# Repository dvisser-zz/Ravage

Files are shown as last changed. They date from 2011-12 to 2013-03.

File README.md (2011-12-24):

# RavAGE - A Toyota 4AGE specific hardware solution for FreeEMS.

### Introduction

The name "RavAGE" is something relating to the Toyota 4-'AGE' engine. The aim of
the RavAGE project is to create a hardware solution for FreeEMS that caters to
the needs of the Toyota 4AGE engines (16V and 20V). It may also be used on most
4/6cyl engine setups with minimal to no modifications required. 

Please see [FreeEMS.org](http://freeems.org) for the most up to date information
and links for this project and all of the other aspects of the FreeEMS project.

### Goals

Core IO specs:

 - 1 FTDI USB (bus powered) communications that are opto coupled to the CPU. 
 - 3 RPM/Position inputs via MAX99xx devices to take advantage of the 3 in the 4AGE CAS assemblies.
 - 8 Standard 'CORE' analogue inputs. 
 - 6 ignition drives (external igniters ONLY).
 - 6 injector drives (high-z ONLY).
 - 5 Ground connections (ECU GND, INJ GND, IGN GND, ACC GND and Analogue Input GND).
 - 3 "12V" connections (+12V CONSTANT,+12V SWITCHED for BRV and key-on signal and +12V ACC for accessory functions).
 - 3 overkill relay drive's (FAN RELAY, FUEL PUMP RELAY and VVT SOLENOID).
 - 1 switched +5V output for TPS and EXT MAP.
 - 2 outputs suitable for driving a 3-wire Toyota Idle Speed Control Valve (+12V ACC, PWM Non-Inverted and PWM Inverted).
 - 2 spare digital inputs.
 - 2 spare analogue inputs (option to configure as temperature or voltage input).
 - 2 spare low side drives.

PCB Size is to be as small as possible, but attention must be paid when choosing
a connector as this will more than likely be the deciding factor on the overall
size. Worst-case scenario will be a PCB that is 100mm x 80mm, which is still
small and allows for the use of some sort of "nice" connector. It could be
made smaller, but at this size, there will be room for extra general purpose
output drivers, analogue inputs, etc.

### Status

For the most up to date status information for the project, refer to the TODO.md
file which is maintained in sync with the schematics by a small team who verify
each other's work.

### Changes

Please send any changes that you make to RavAGE back upstream to [Dan Visser's copy](https://github.com/dvisser/Ravage)

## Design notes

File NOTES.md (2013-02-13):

# Design Detail Notes

This file is to contain various details that aren't appropriate to show in the
schematic such as default specifications for passive components and deviations
from those defaults.

 - Unless otherwise noted, all resistors to be 1% metal film construction and 100mW power handling.
 - Pull up resistors on thermistor inputs, voltage measurement divider networks, and regulator V setting network to be 0.1% metal film.
 - Capacitors 1.0uF and under to be X7R ceramic, and in very small values, C0G/NP0.
 - All polarised capacitors are tantalumn, 35V minimum when exposed to battery voltage, 10V minimum for internal regulated voltages.
 - VR input resistors to be 200V rated and have a power rating of 500mW or greater. 
 - VR input capacitors must be 200V rated. 
 - VR 5k shunt resistor must be 2W or greater
 - ADC 470R current limiting resistors must be 250mW or greater. 
 - Ignitor drive output 200R current limiting resistors must be 2W or greater. 
 - Ferrite bead to 5V USB input before caps to prevent USB power noise corrupting comms should be something like this: http://nz.element14.com/murata/blm18pg300sn1d/ferrite-bead-0603-case-30ohm/dp/1515741RL
 - 1k input resistor and 5v6 zener on digital input circuits should be rated to 250mW minimum.
 - All LEDs should have 2.4k resistors except where noted in the schematics.
 - For best ADC accuracy, ensure that "+5V SWITCHED" voltage is less than or equal to "+5V MICRO" 
 - After construction measure quiescent current and ensure that it's below ~100mA. If not the clamp and power supply are probably fighting. Look at the 5V rail, if high, tweak resistors to trim it down, if not, tweak clamp resistors to trim it up.

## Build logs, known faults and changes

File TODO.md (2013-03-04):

### TODO

Items listed here should be changed one at a time, and the line marked done, this
file and the changed files committed together. After a session of N changes the
PDF should be updated and pushed. The PDF should not be updated with each and
every change as there is no benefit and a binary repository size drawback.

 - Fred and Dan to discuss/review reverse polarity behaviour of the current schematic and connection topology. Next skype.
 - Correct lables on RPM1a inputs, which are backward. Spotted by Dan, good work, sir! :-)
 - DONE, Fix the load jumper and CEL circuit by adding a resistor between it and the CPU like this: http://stuff.fredcooke.com/LoadAndCELCorrectJumperTopology.png
 - Deferrable: Spend some time to properly tune the ADC filter capacitor values - Fred and Dan and others
 - Deferrable: Experiment with layouts to validate pin arrangement selection for header, and decide if Knock/RS232/Dual-reg setup is possible to fit for 0.1

### Once branched for layout-0.1-alpha (RC2)

Fred and Dan to do this together like last time in a session.

 - Remove the SD card sheet, 3.3V power supply, and X the pins on the CPU sheet, etc.
 - Correct annotation sheet order before annotating
 - Annotate the schematics with designators
 - Update all notes with designators to match new numbering (remove ?)
 - Generate new PDF for review
 - Update the TODO to reflect current goals on branch and new single hash of all files post annotation
 - Tag repository as Schem-0.1-alpha-RC2
 - Import BOM from RC1, adjust references to suit new schematic annotations, commit BOM (do we need PDF of this? I think not.)

### Still To Add/Do

Known issues which don't have a solution 100% nailed down yet.

Required for a final board revision to be top quality:

 1. Confirm pin selection for simple bit banged IO like tacho etc: Fred + others: http://forum.diyefi.org/viewtopic.php?f=8&t=1676
 2. Finalise selection of wakeup pin - Fred http://forum.diyefi.org/viewtopic.php?f=8&t=1266
 3. Power supply page - requires design, discuss http://forum.diyefi.org/viewtopic.php?f=58&t=1478

Easy stuff to do last:

 1. Tune the ADC input filters - Fred + consultation
 2. Annotate all components in the schematics
 3. Add to and correct the NOTES.md file

Stuff that's still in progress, but good enough already:

 1. DONE! (enough) Develop new improved SM - Fred http://forum.diyefi.org/viewtopic.php?f=8&t=1232

And perhaps more.

### SD card sheet changes

Discuss all SD card sheet changes before doing anything, skype, IRC and forum: http://forum.diyefi.org/viewtopic.php?f=58&t=1479

 - Improve layout of SD card sheet - Preston wants to do this
 - Move 3.3V regulator to 12V input such that sharp current changes don't affect our analogue stuff
 - Use regulator with enable input and parallel with analogue enable on 5V setup
 - Reduce post reg capacitor to 47uF tantalum
 - Change 1.0uF to 0.1uF ceramics on both sides of 3.3V reg
 - Move all 3.3V power supply caps to power supply sheet

All pages that are changed must be rechecked and enter another cycle of fix and
then check or be confirmed good and then locked down.

### Connector pin ordering

At least four concerns guide the selection of pin to function mappings. By far
the most important of these is noise considerations. For this reason the layout
should maintain the following block ordering:

 1. RPM Inputs (hyper sensitive)
 2. Analogue Inputs (and 5V/Ground for them) (very sensitive)
 3. Digital Inputs (very sensitive)
 4. Ignition Outputs, low current (not sensitive, not noisy)
 5. Fuel pump relay drive (not sensitive, potential to be noisy)
 6. Spare LSD Outputs (not sensitive, usually noisy, when used)
 7. ISCV Outputs (not sensitive, usually noisy, when used)
 8. Injector Outputs (not sensitive, always noisy, when used)
 9. Power and Grouds (not sensitive, grounds always noisy)

The other three concerns are these:

 1. Intuitive User Order
 2. Fine grain routing
 3. Schematic Aesthetics

1 and 2 are of similar importance, and 3 should take a back seat to the others,
while still being kept in mind for ease of comprehension. As such the designers
are free to reorder pins of this sheet during the layout process to facilitate a
better, lower noise, simpler, cleaner, more compact, more comprehensible for the
user layout. Aside from the block ordering, the page should be kept with all
inputs and ignition drivers on the left and all high current and high noise
connections on the right. This sheet reordering does not need to follow the
usual process of agree, TODO, action, and can be done at the designers will.
Although this breaks with the process, it provides significant benefits in both
speed of development and quality of development. Thus it is worth doing this way.

The spare pins header sheet is subject to the same freedoms for layout reasons.

Pin ordering follows this diagram, except the grounds have been rearranged http://stuff.fredcooke.com/RavagePinOutAttempt2.png

### Pre-Layout Lock Down

As each sheet becomes a perfect representation of what we want to see in RavAGE
it will get locked. That is to say, no further changes to that sheet's source
.SchDoc file will be allowed without agreement between all key players.

Locked sheets will be listed here as they are finalised:

 - Spare IO Header @ NO pending possible rearrangement
 - Core analogue inputs @ NO pending value selection
 - Extra analogue inputs @ NO pending value selection
 - USE 0.1 TO TEST: @ b36bb33d Digital and wake up inputs @ NO pending wake up testing
 - Connector pin out @ ecdaed700b58eaaf16ad0ddf4c48198efca5d85a
 - CPU and buses, etc @ 14eae84ad1f2c094e9d5b6bee46bd3429c172d74
 - USB communications @ e70d478d8635a083402ecfb5f5f076b4fc3c8185
 - RS232 communications @ 247e1f109145382aaa98ed5c90c7676b9f4068cd
 - RPM conditioned inputs @ c40a0885fad16cf92aaf213e950141aef8fa67e1
 - Knock sensor inputs @ 1450ad98dc2e1c864d0d5789b42a16420bbd773e
 - Igniter output drivers @ fc591f538e7f880f76d490ce6b23da58f4e1e481
 - Injector output drivers @ 7ad534dc22ba7a4618d42d22ae2bb547ddda230f
 - GP low side drivers @ 0e0ec7b1f4f0095ec0caf7929a33b819e120481e
 - 3-wire ISCV drivers @ 7ad534dc22ba7a4618d42d22ae2bb547ddda230f
 - OK FOR 0.1 @ e50be379d But not final. Power supplies @ NO pending discussion and design
 - UNUSED FOR 0.1: SD card slot @ NO pending multiple changes

### PDF Sheet Ordering

All sheets except for the CPU/navigation sheet will be A4 size. The CPU sheet
needs to be larger to fit the minimum required items on it. The sheet ordering
should be kept consistent on every commit. Preferred ordering is as follows.

 1.  CPU, decoupling, etc
 2.  Power supplies
 3.  USB communications
 4.  RS232 communications
 5.  RPM conditioned inputs
 6.  Core analogue inputs
 7.  Extra analogue inputs
 8.  Digital and wake up inputs
 9.  Knock sensor inputs
 10. Igniter output drivers
 11. Injector output drivers
 12. GP low side drivers
 13. 3-wire ISCV drivers
 14. SD card slot
 15. Spare IO Header
 16. Connector pin out

### Space Constraints

Due to the target board size and the level of things included so far, some
items could get cut when layout starts and we start getting a feel for
realistic limitations. The current plan is a 2-layer board with all features
that are currently in the schematics. I will list the possible changes below.

 - Change from 2-layer to 4-layer. Benefits more compact, better noise resistance. Drawbacks, more expensive, mildly less hackable.
 - Remove SD card slot and 3.3V power supply components
 - Remove RS232 interface for LC-1 and other products
 - Remove knock sensing interface circuit
 - Drop always-on support and RTC in favour of a simpler key switched design
 - No built in BDM header included, program via bed of nails or edge connector
 - Less spare and GP and diagnostic drivers and protection circuits
 - Less injector and ignition drivers, 4 minimum each, optimally 6 ignition, 8 injection

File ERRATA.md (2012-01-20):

# RavAGE Errata

The project is still under development so, by definition, there is no errata yet.

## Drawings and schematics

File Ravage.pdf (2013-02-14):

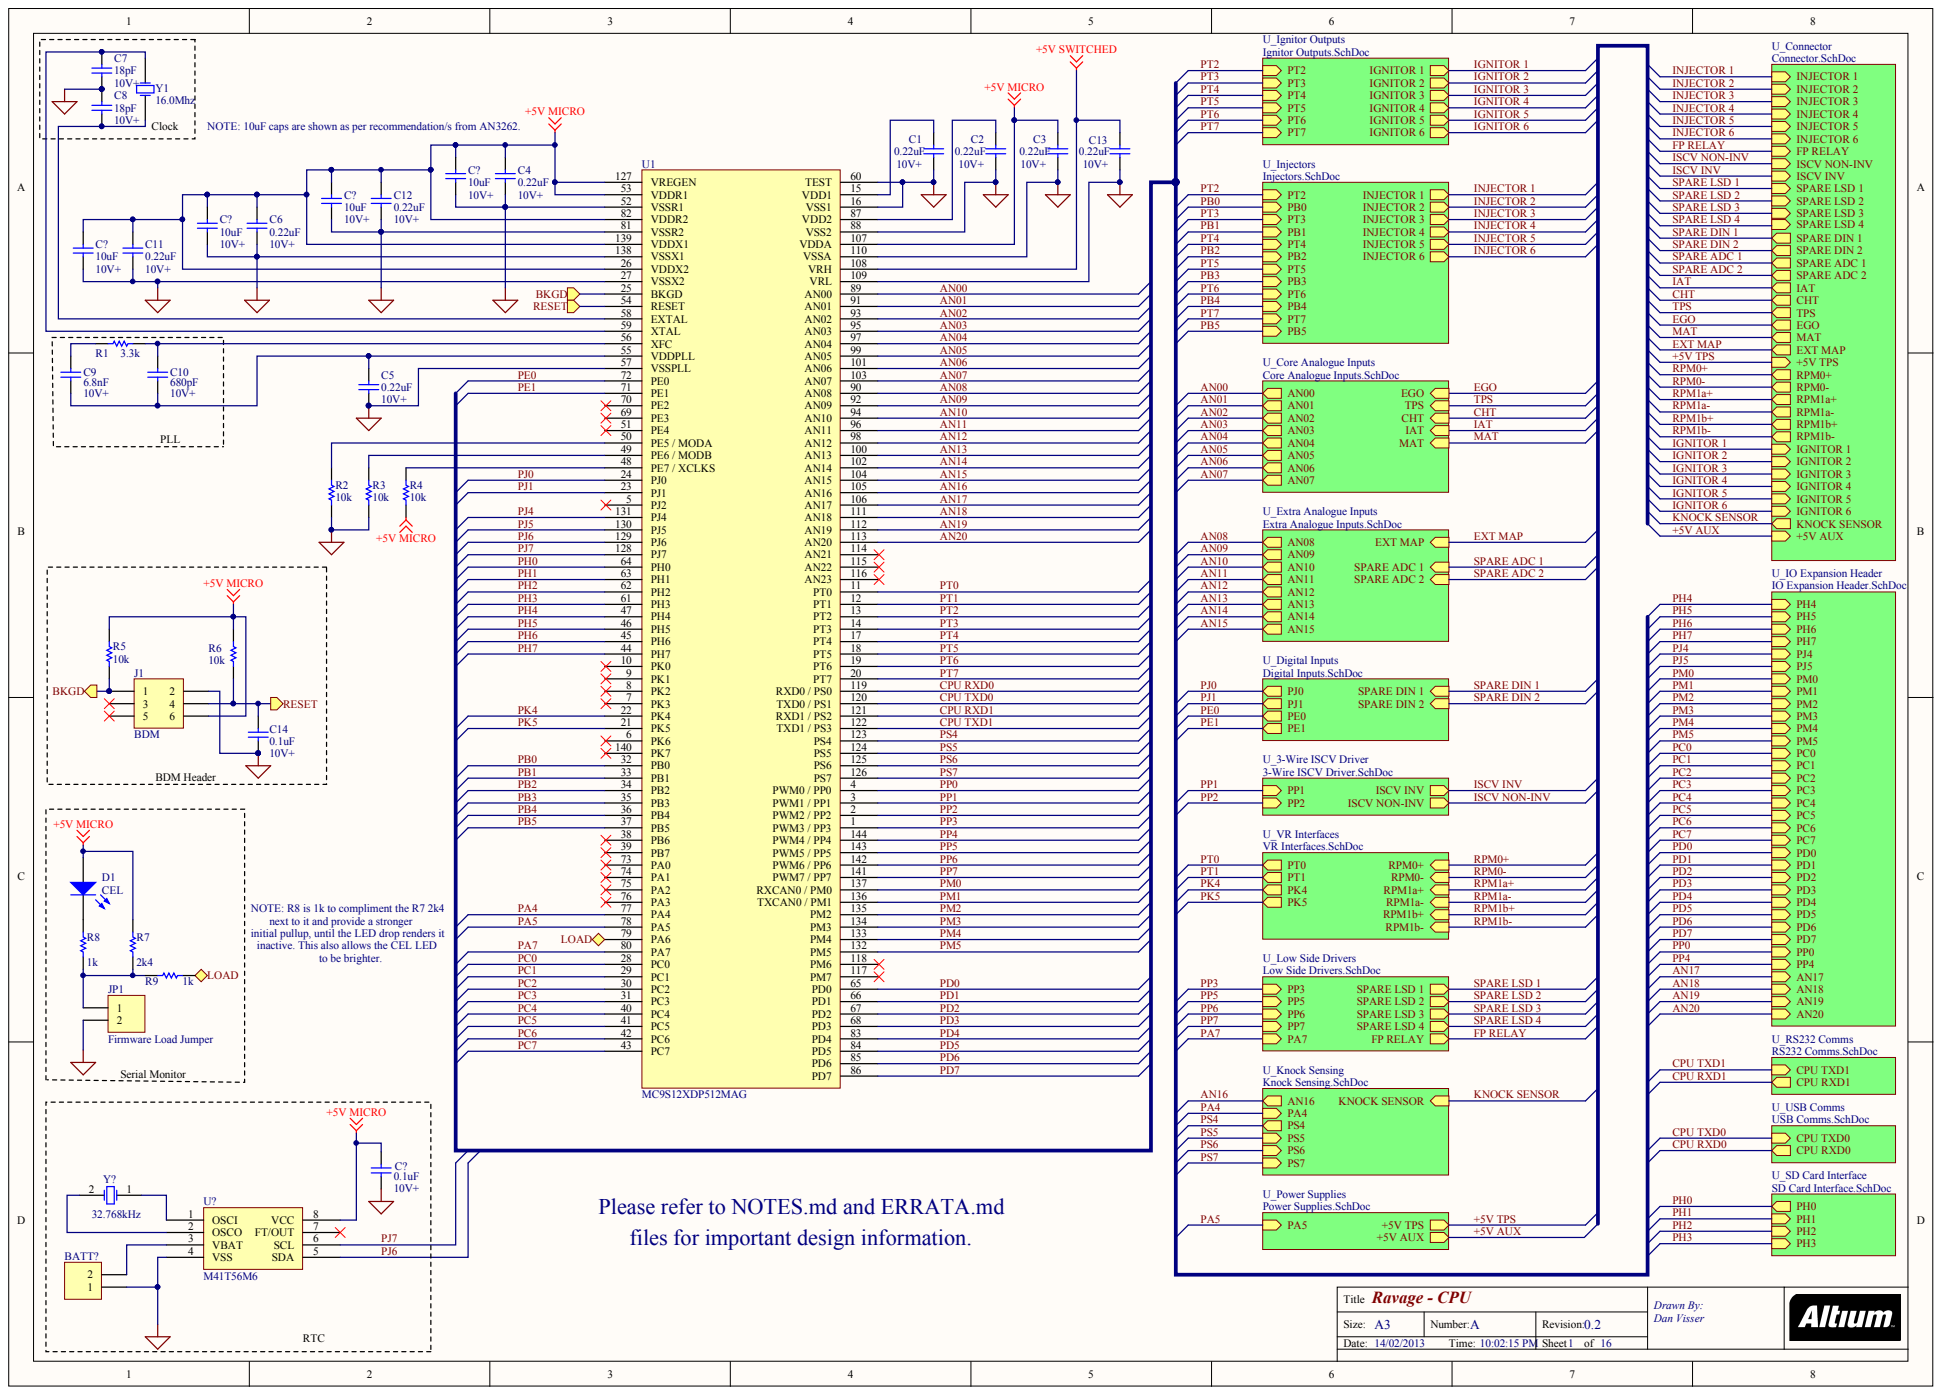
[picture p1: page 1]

INJECTOR 1
INJECTOR 2
INJECTOR 3
INJECTOR 4
INJECTOR 5
INJECTOR 6 SPARE LSD 3 FP RELAY SPARE LSD 4

own as per recommen

ISCV NON-INV
ISCV INV SPARE LSD 1 SPARE LSD 2

IGNITOR 6 SPARE LSD 3

5 2
8 2 | | 8 7

EXT MAP SPARE ADC 1 SPARE ADC 2 SPARE DIN 1 SPARE DIN 2
IGNITOR 1 SPARE DIN 2 SPARE ADC 1 SPARE ADC 2

1 3 9 | 1 0 7
1 3 8 | 1 1 0
2 6 | 1 0 8
2 7 | 1 0 9

EXT MAP MAT SPARE ADC 1 SPARE ADC 2 SPARE DIN 1 SPARE DIN 2

4 9
4 8
2 4

3-Wire ISCV Driver
3-Wire ISCV Driver.SchDo

NOTE: R8 is 1
next to it an
initial p
inactive. This also allows the CEL LED

k to compliment the R7 2
d pro
ntil the LED dro

U_Low Side Drivers
Low Side Drivers.SchDo

PARE LSD 1
PARE LSD 2
PARE LSD 3 FP RELAY
PARE LSD 4

Please refer to NOTES.md and ERRATA.m
files for important design information.

Drawn By: Da n Visser

A3 | Revisio n :

Date: 4/0 2/2 Time: 0:0 2:1 5 P M | S heet o f

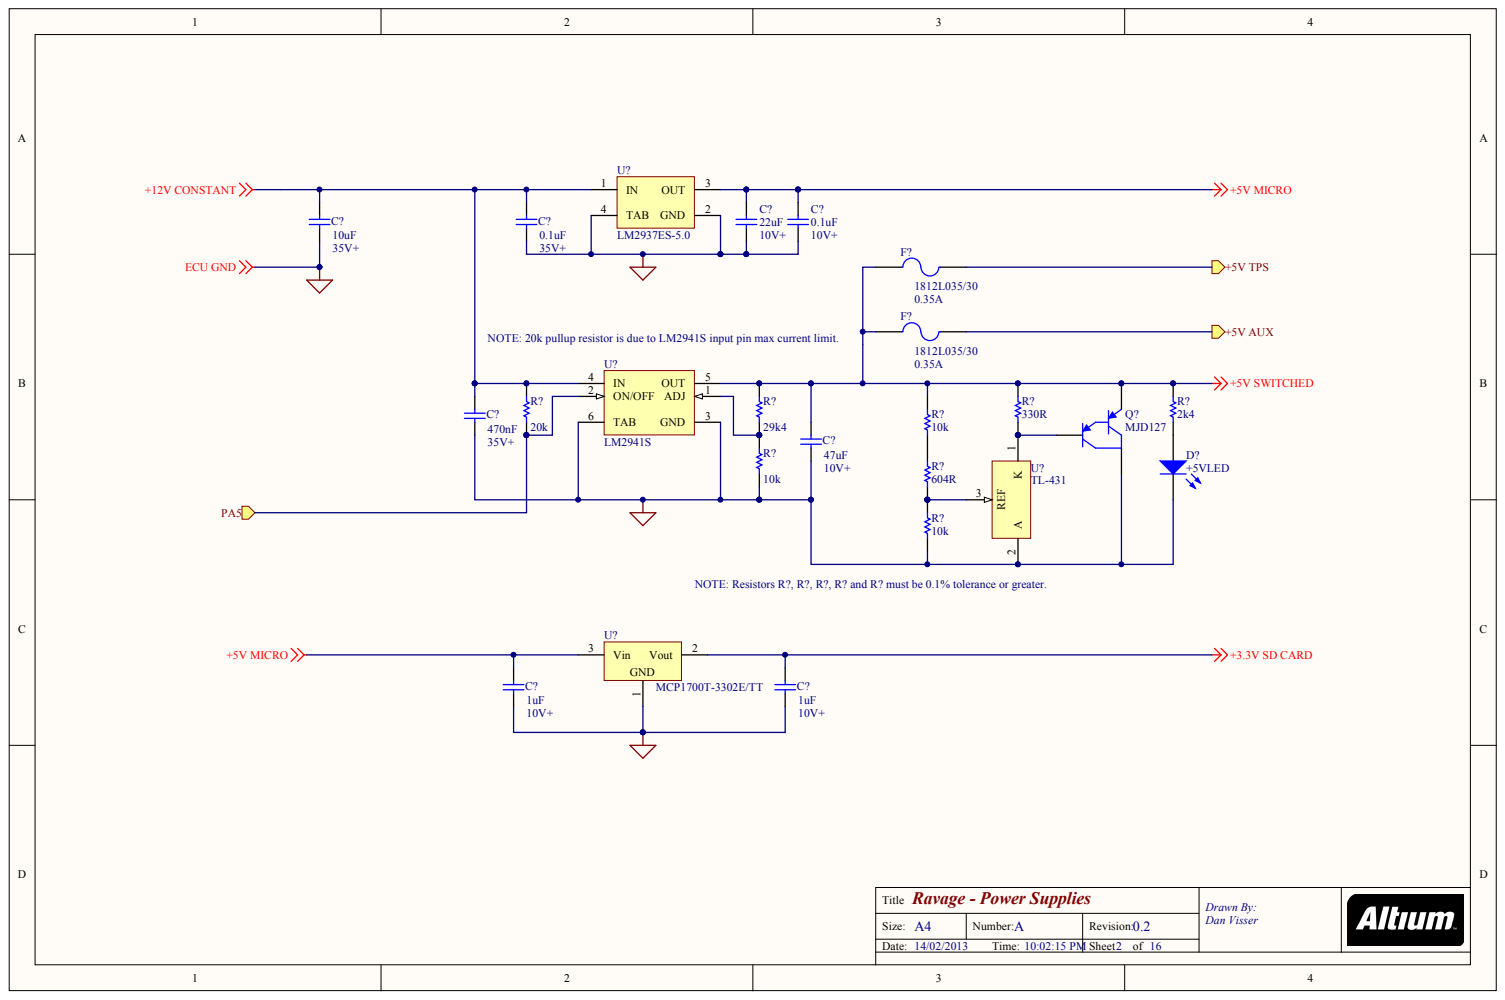
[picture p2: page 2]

NOTE: 20k pullup resistor is due to LM2941S input pin max current limit.

NOTE: Resistors R?, R?, R?, R? and R? must be 0.1% tolerance or greater.

Drawn By: Dan Visser

A4 | Revision:
14/02/2013 10:02:15 P | Sheet of

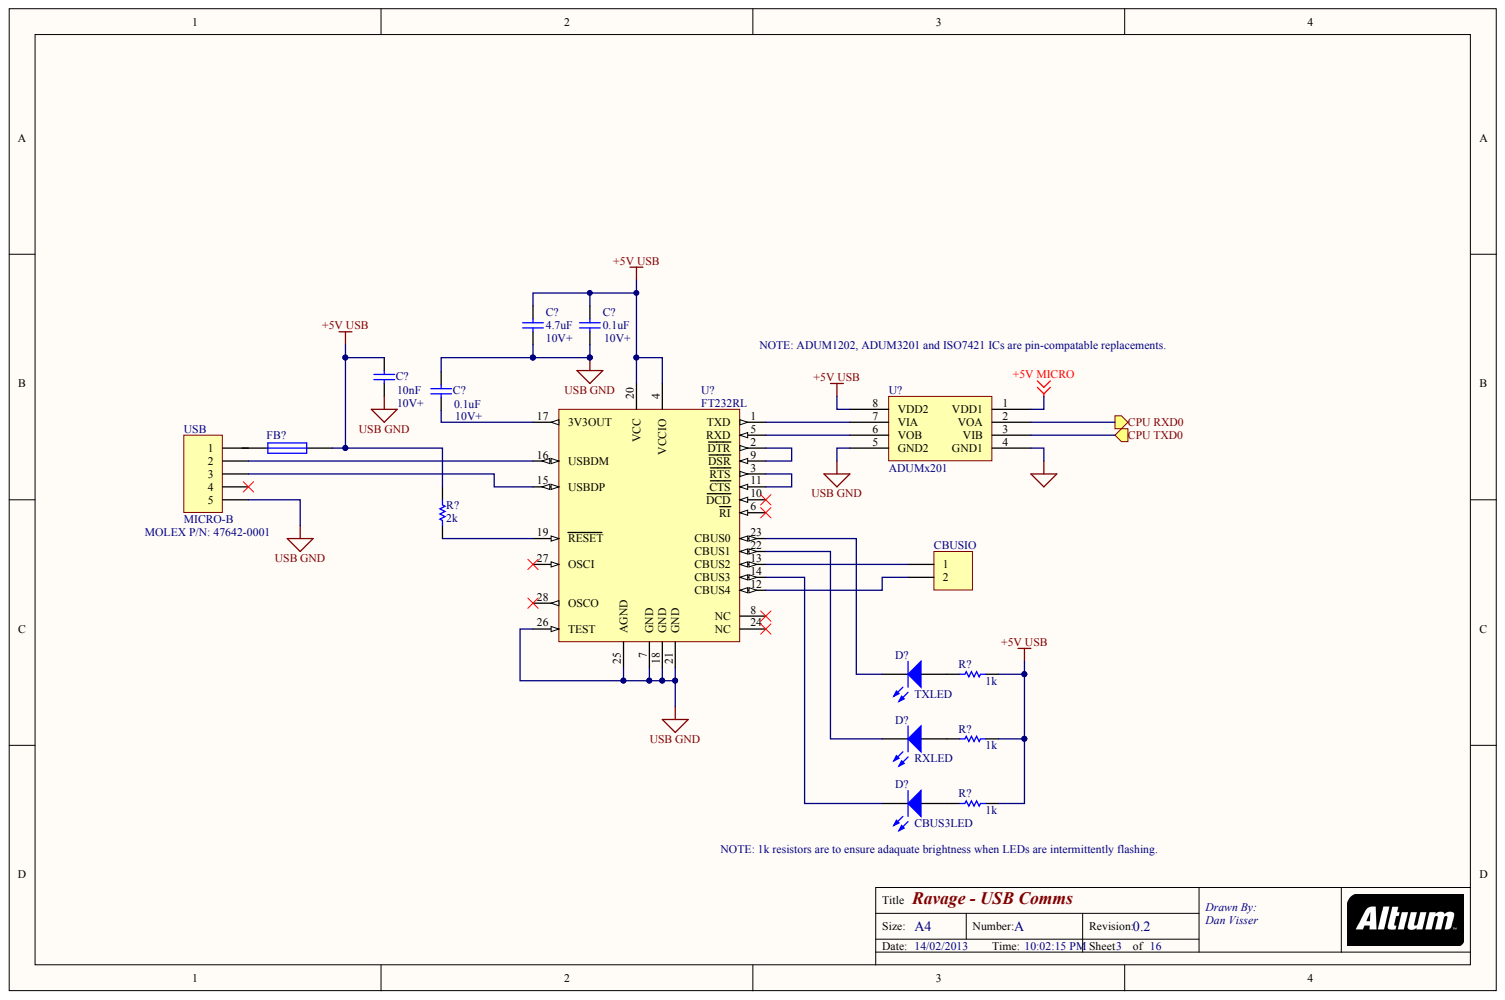
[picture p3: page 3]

NOTE: ADUM1202, ADUM3201 and ISO7421 ICs are pin-compatable replacements.

NOTE: 1k resistors are to ensure adaquate brightness when LEDs are intermittently flashing.

Ravage - USB Comms Title | Drawn By: Dan Visser

Size: A4 | Number: A | Revision: 0.2
14/02/2013 Time: 10:02:15 PM | | Sheet of

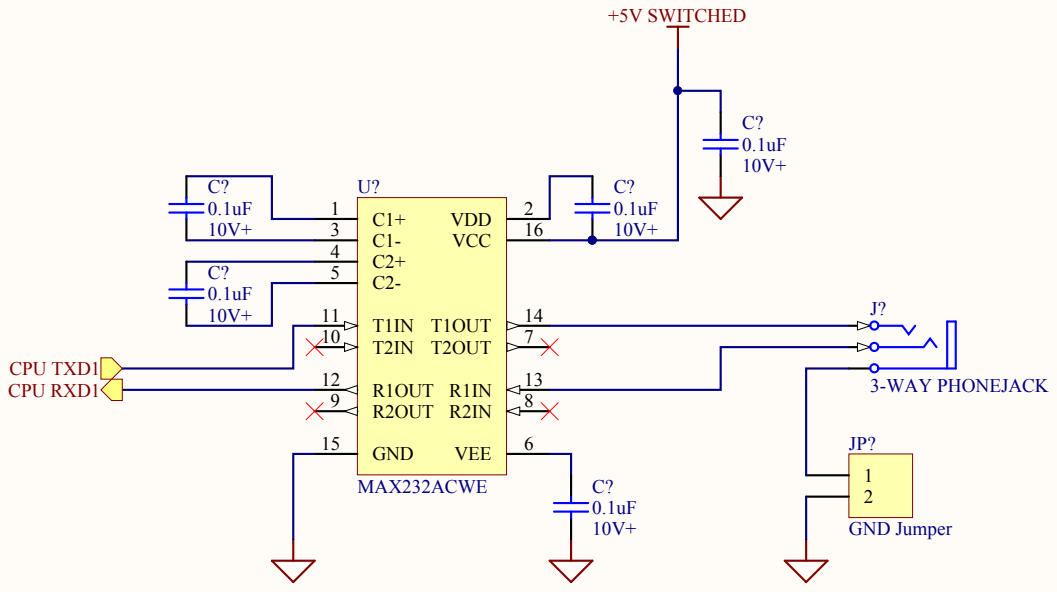
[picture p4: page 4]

Drawn By: Dan Visser

A4 | Revision:
14/02/2013 10:02:16 P

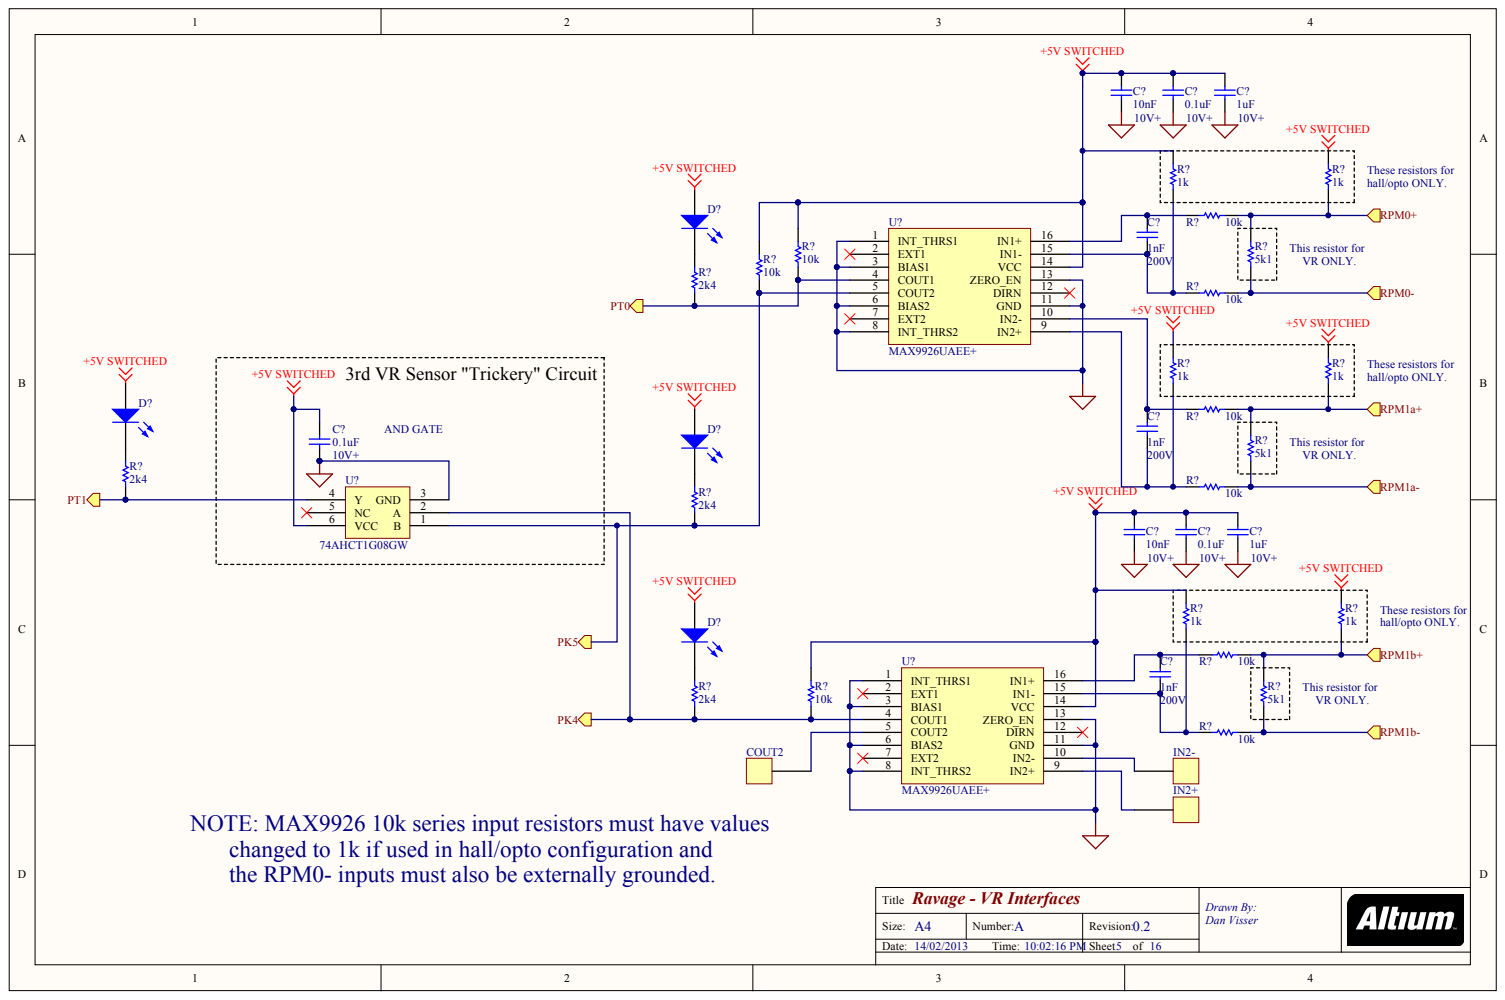
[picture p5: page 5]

3 | | | | 200V

+5V SWITCHED 3rd VR Sensor "Trickery" Circuit

NOTE: MAX9926 10k series input resistors must have values
changed to 1k if used in hall/opto configuration and
the RPM0- inputs must also be externally grounded.

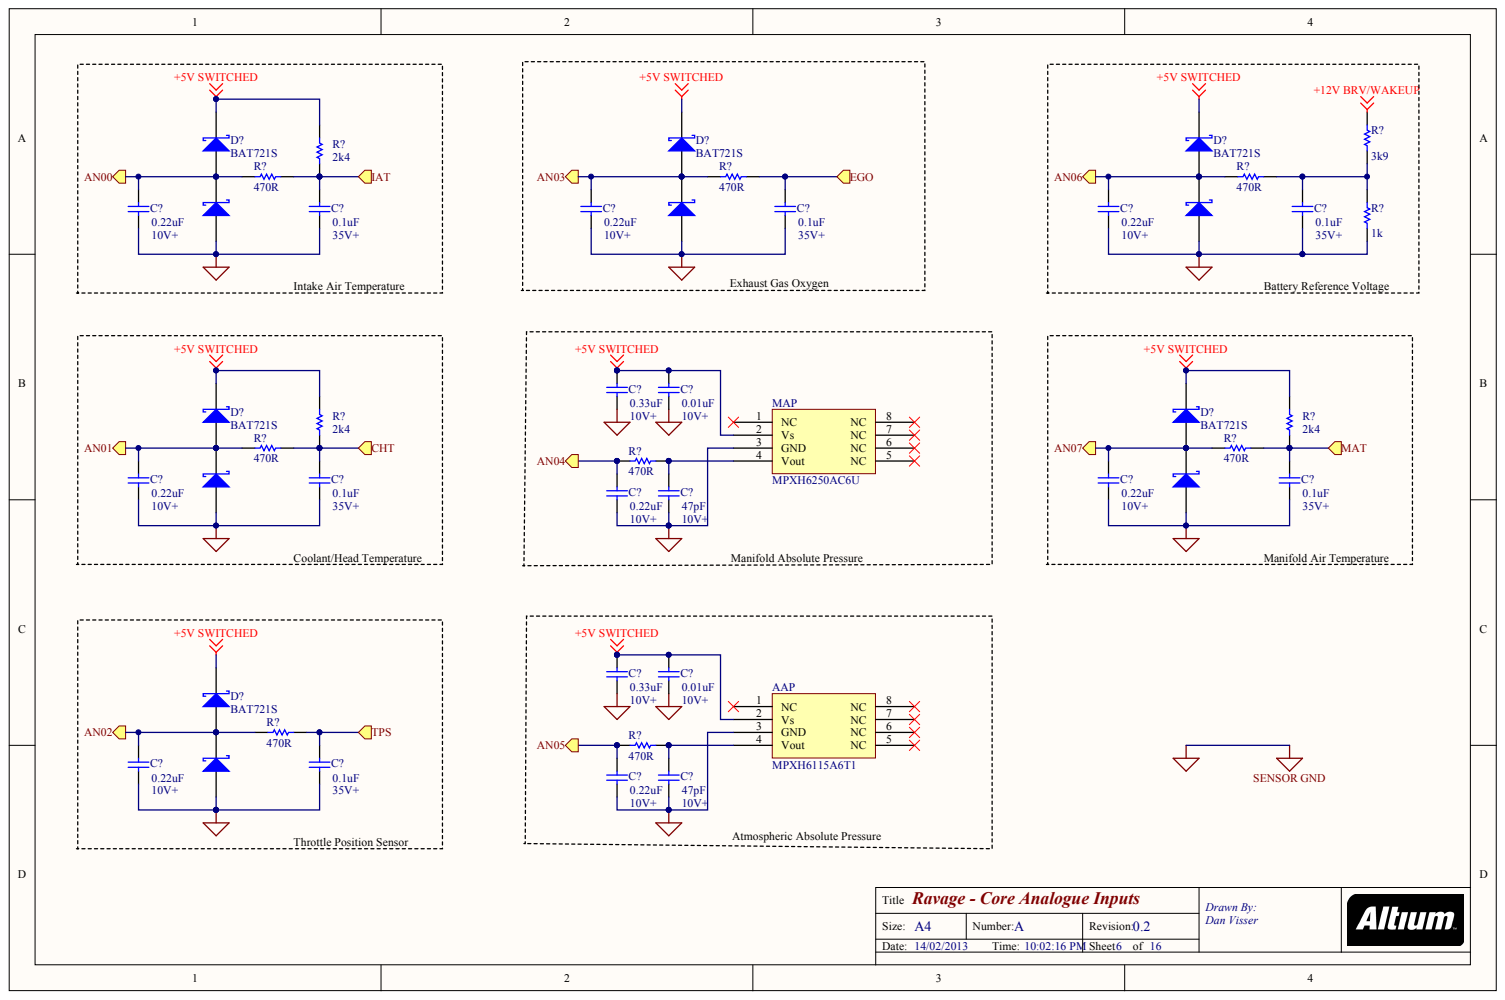
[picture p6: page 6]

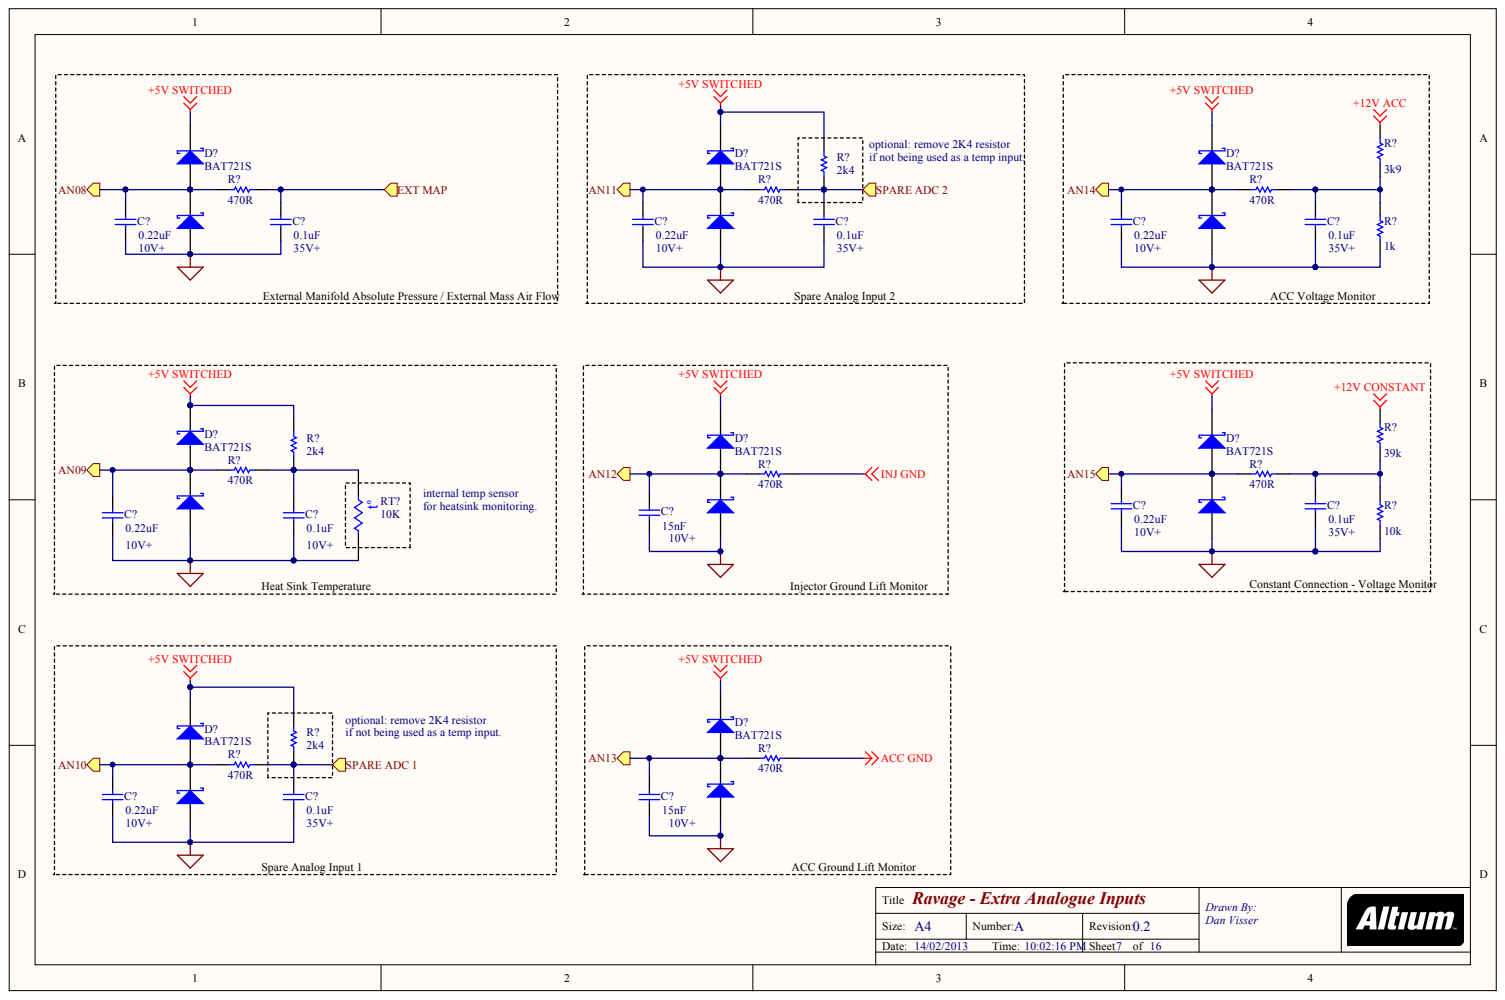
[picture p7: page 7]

optional: remove 2K4 resistor
if not being used as a temp input.

External Manifold Absolute Pressure / External Mass Air Flow

Constant Connection - Voltage Monitor

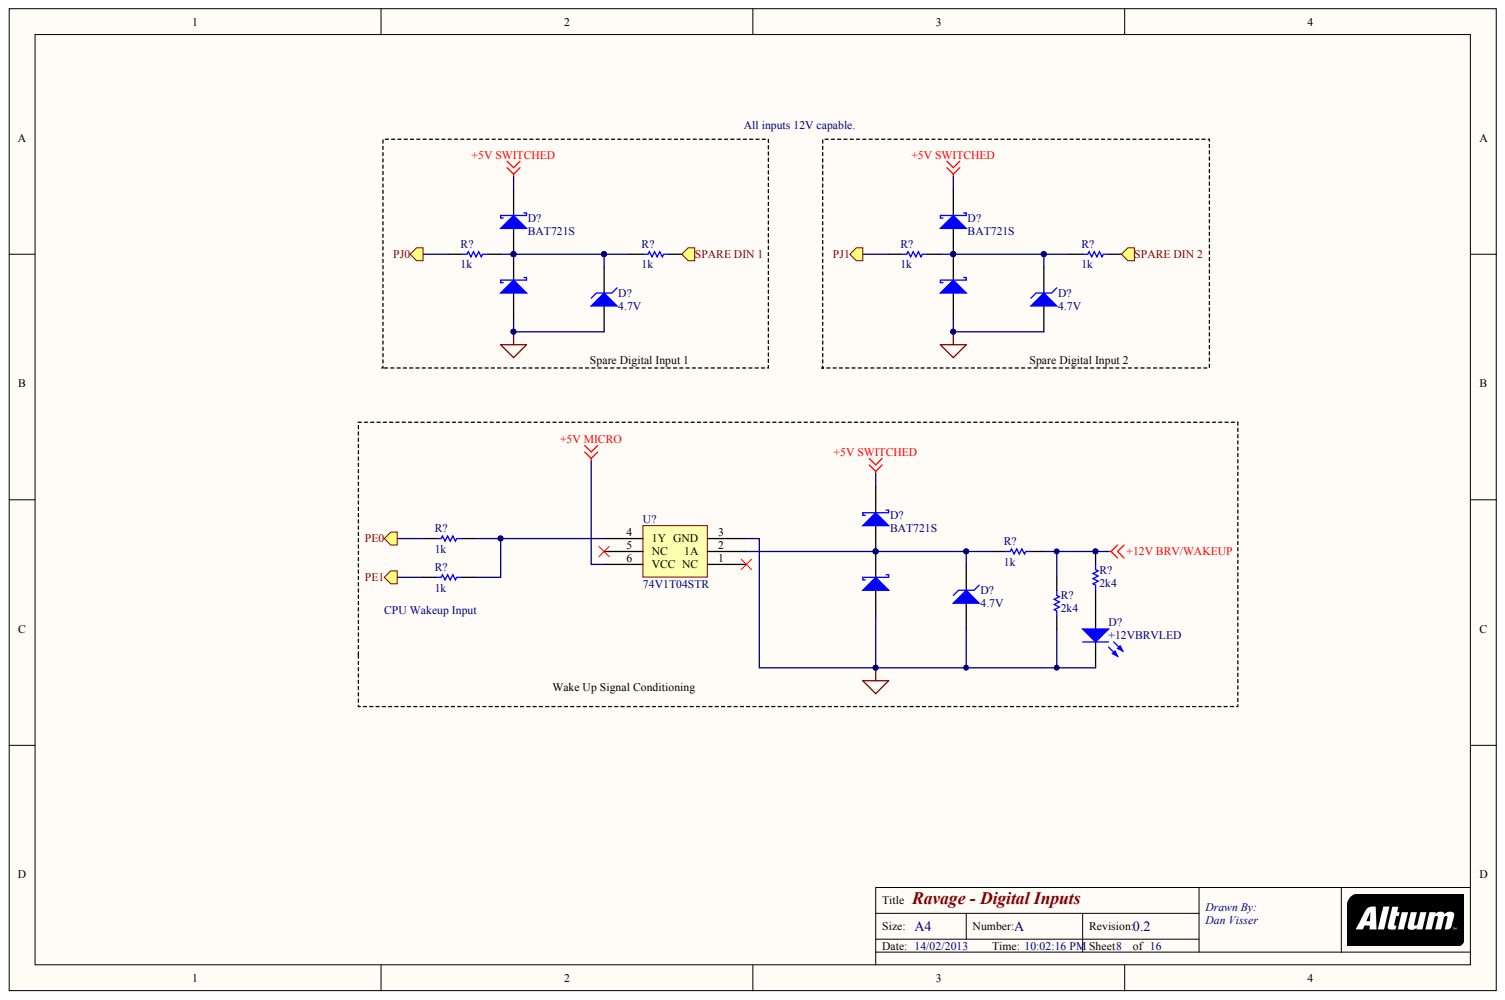
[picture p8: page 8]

Wake Up Signal Conditioning

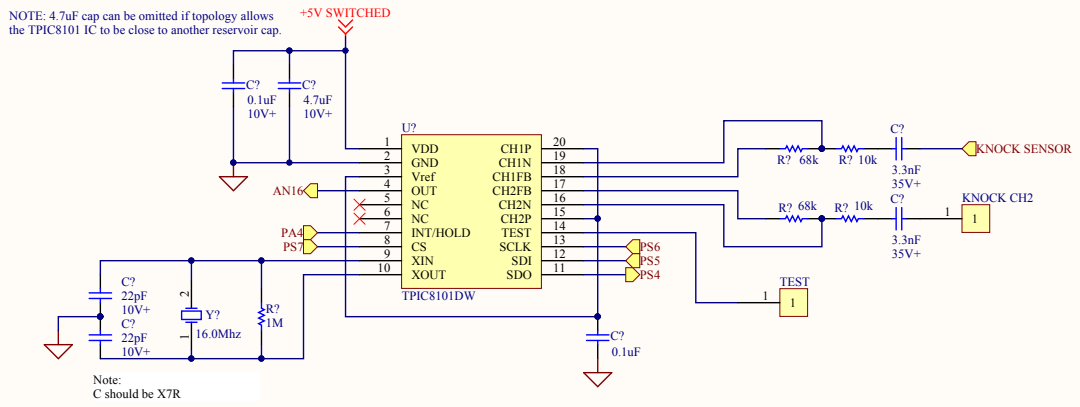
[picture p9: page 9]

NOTE: 4.7uF cap can be omitted if topology allows
the TPIC8101 IC to be close to another reservoir cap.

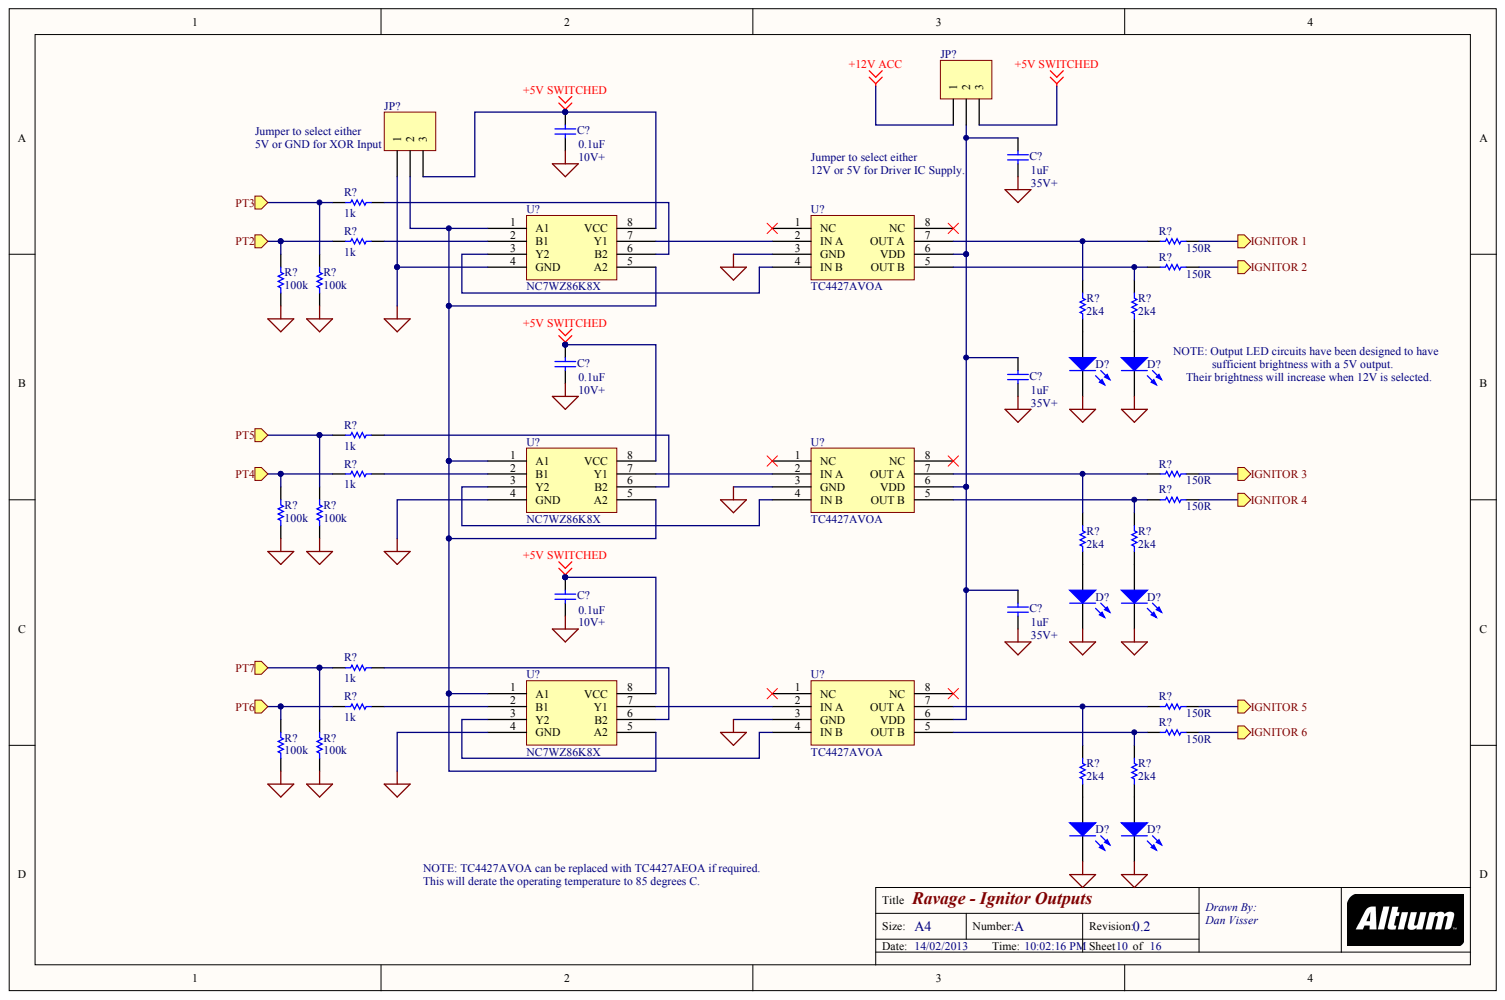
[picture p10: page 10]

Jumper to select either
5V or GND for XOR Input

12V or 5V for Driver IC Supply.

NOTE: Output LED circuits have been designed to have

sufficient brightness with a 5V output.
Their brightness will increase when 12V is selected.

GND

NOTE: TC4427AVOA can be replaced with TC4427AEOA if required.
This will derate the operating temperature to 85 degrees C.

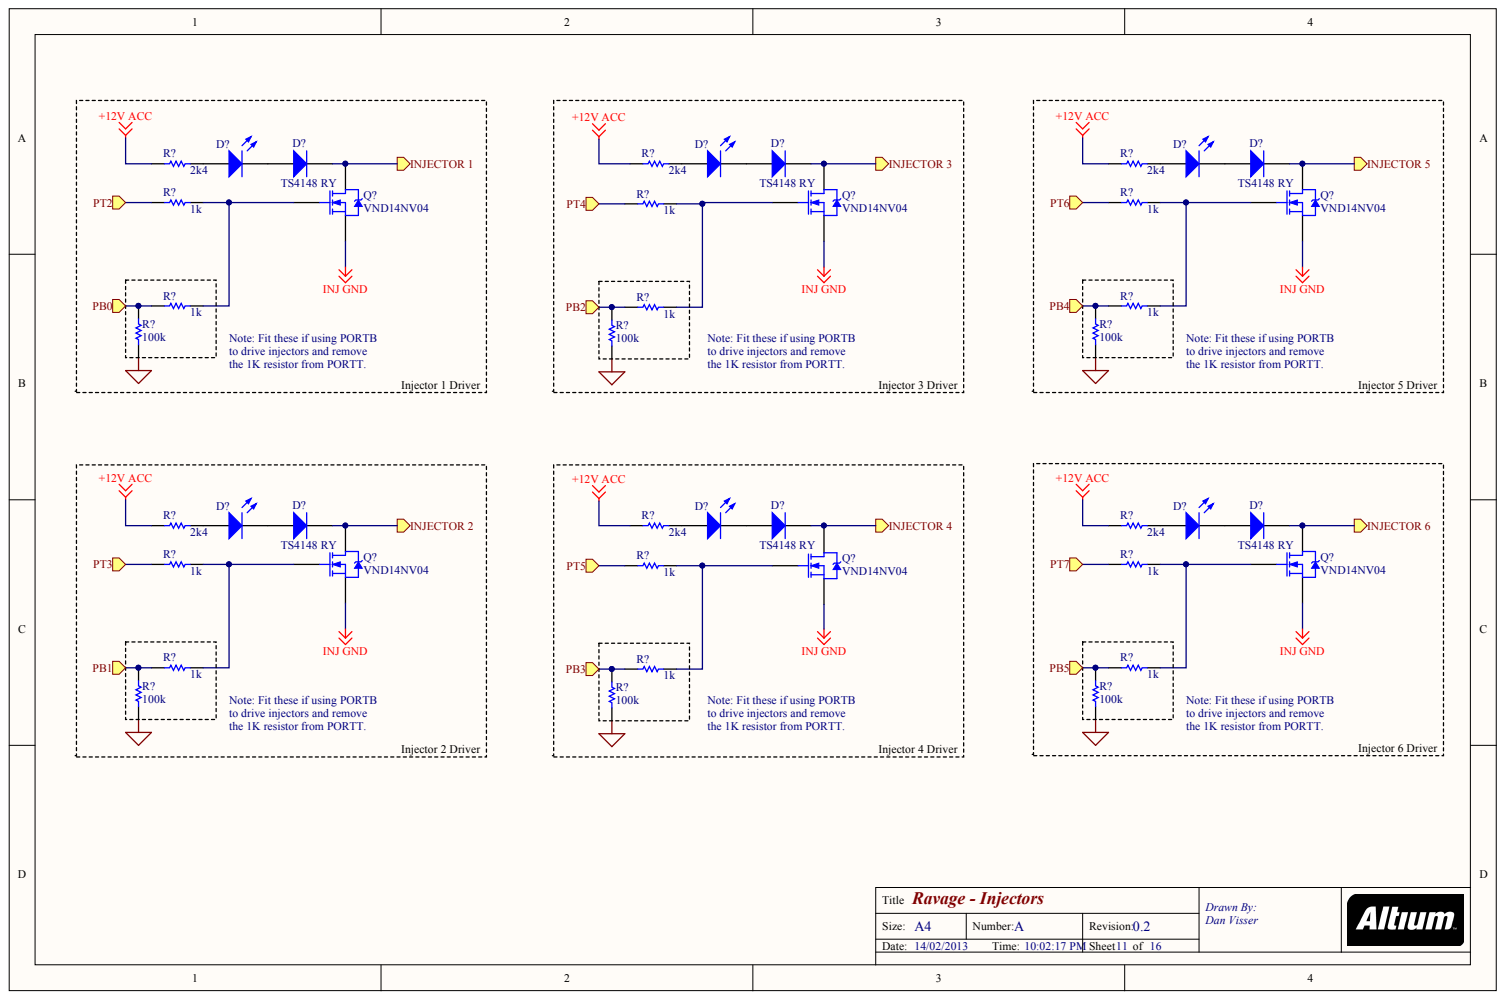
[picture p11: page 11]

Note: Fit these if using PORTB
to drive injectors and remove
the 1K resistor from PORTT.

Ravage - Injectors Title | Drawn By: Dan Visser

Size: A4 | Number: A | Revision: 0.2
14/02/2013 Time: 10:02:17 PM | | Sheet of

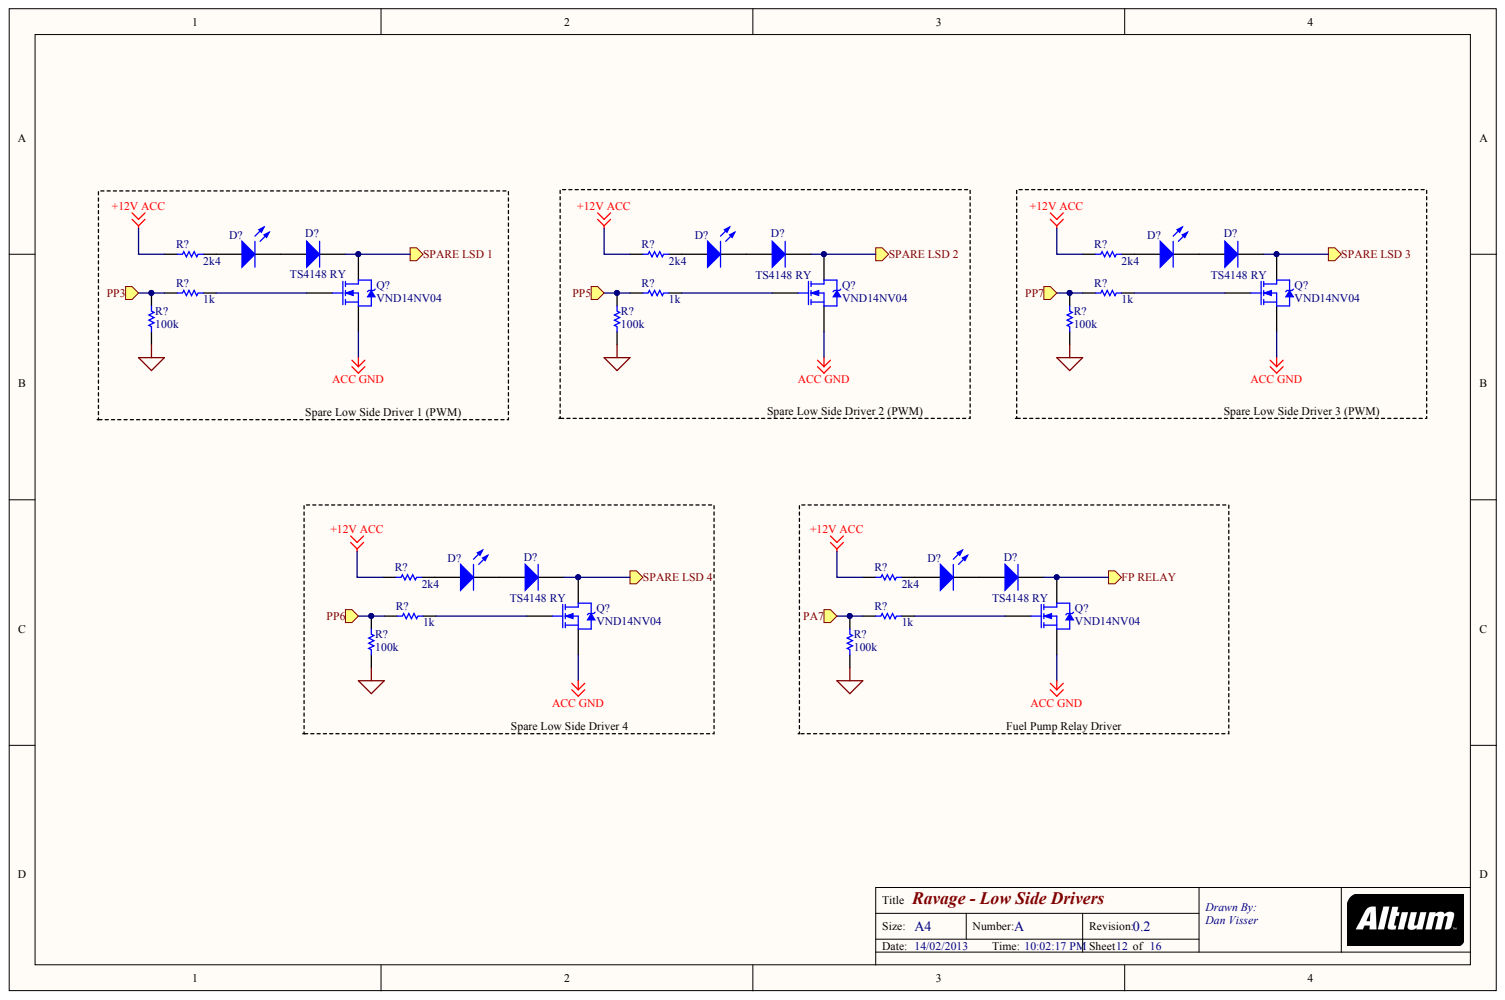
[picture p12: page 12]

Ravage - Low Side Drivers Title | Drawn By: Dan Visser

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


NOTE: Only one 1k resistor above is to be fitted.
This allows independant use of the FET for normal purposes.

Ravage - 3-Wire ISCV Driver Title | Drawn By: Dan Visser

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


Drawn By: Dan Visser

A4 | Revision:
14/02/2013 10:02:17 P


Drawn By: Dan Visser

A4 | Revision:
14/02/2013 10:02:17 P


NOTE: L and M pins are rated at 12A max, with remaining pins rated at 6A max.

+12V ACC
ISCV INV SPARE LSD 1 SPARE LSD 2
INJECTOR 6 SPARE LSD 3
INJECTOR 5
INJECTOR 4

Drawn By: Dan Visser

A4 | Revision:
14/02/2013 10:02:17 P

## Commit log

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2011-07-09 Reduce the number of power and ground pins required. BRV and key-on can both be the same relay switched clean power sourced from the battery and the relay controlled by the key directly. I will make 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
2011-07-12 Corrected FTDI chip for bus powered mode. Fixed incorrect LED connections. Added opto-isolators which should assist in holding the CPU RX pin logic high whilst the FTDI IC is de-powered.
    [USB Comms.SchDoc]
2011-07-13 Changed power rail symbols to off-sheet connectors as they should of been. Also changed OR gate to XOR.
    [VR Interfaces.SchDoc]
2011-07-13 Changed power rail symbols to off-sheet connectors as they should of been. Also changed FET to SMD type and not TO-220.
    [Low Side Drivers.SchDoc]
2011-07-13 Changed power rail symbols to off-sheet connectors as they should of been. Also added in another +12V input to the ECU for +12V IGN as I want the driver chips that feed the igniters to have a bit mor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
    [Igniter Outputs.SchDoc]
2011-07-13 Changed power rail symbols to off-sheet connectors as they should of been.
    [Digital Outputs.SchDoc]
2011-07-13 Changed power rail symbols to off-sheet connectors as they should of been. Also added decoupling cap to cpu RESET line.
    [CPU.SchDoc]
2011-07-13 Changed power rail symbols to off-sheet connectors as they should of been. Also added support for External BOSCH MAP sensors.
    [Analog Inputs.SchDoc]
2011-07-13 Changed power rail symbols to off-sheet connectors as they should of been. Changed FET to SMD type and not TO-220.
    [3-Wire ISCV Driver.SchDoc]
2011-07-13 Changed what CPU pins are used for ignition and injection. Ignition outs are now PT2 and PT3 and injector outs and now PT4, PT5, PT6 and PT7.
    [Igniter Outputs.SchDoc, Injectors.SchDoc]
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2011-07-23 Corrected SPARE ADC numbering.
    [Analog Inputs.SchDoc]
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2011-07-23 Corrected protection on inputs and updated amount of them.
    [Digital Inputs.SchDoc]
2011-07-23 REMOVED - No longer required by RavAGE SPIN 1.
    [Digital Outputs.SchDoc]
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2011-07-23 Put injectors on same PORTT channels as Igniter Outputs. Changed QTY to 6.
    [Injectors.SchDoc]
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2011-07-23 Removed VR SPARE. Allocated correct CPU pin to monitor 3rd VR output state.
    [VR Interfaces.SchDoc]
2011-07-23 Corrected opto connections, opto IC may be changed soon though because of current requirements.
    [USB Comms.SchDoc]
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2011-07-23 Updated labelling to RPM0, RPM1a and RPM1b as per email from Fred.
    [VR Interfaces.SchDoc]
2011-07-23 Added connector sheet showing how the 20-way and 24-way MOLEX headers are connected.
    [Connector.SchDoc]
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2011-07-24 MPX sensors changed to SSOP8. Component values changed and EXT MAP circuit simplified.
    [Analog Inputs.SchDoc]
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2011-07-26 Pressure sensor schematic footprints altered to suit SSOP package and filter circuit altered to suit SSOP device datasheet.
    [Analog Inputs.SchDoc]
2011-07-26 Corrected 2.5V CPU pin connections.
    [CPU.SchDoc]
2011-07-26 Added connector sheet for Molex connectors, but may not stay as Molex Mini-fit series.
    [Connector.SchDoc]
2011-07-26 Corrected filter/protection circuits.
    [Digital Inputs.SchDoc]
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2011-07-26 Diagnostic LEDs added and pullup resistors added to +ve RPM input pins on MAX ICs.
    [VR Interfaces.SchDoc]
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2011-07-28 Added 1K resistor to input side of inverter IC. Moved feed to the added resistor, to the CPU pin.
    [3-Wire ISCV Driver.SchDoc]
2011-07-28 Added internal temp sensor input. Added note on optional components. Added INJ GND and ACC GND monitoring inputs. Changed sheet size from A4 to A3.
    [Analog Inputs.SchDoc]
2011-07-28 Changed ADC volt reference pin connection from +5V MICRO to +5V SWITCHED. Changed SM/load/run pull up resistor to 2K4 from 2K. Changed NET labels of TX and RX pins for clarity.
    [CPU.SchDoc]
2011-07-28 Changed LED supply to +12V ACC. Added optional components to allow using PORTB to drive injectors.
    [Injectors.SchDoc]
2011-07-28 Changed NET labels for TX and RX CPU pins to match same change in CPU sheet. Isolated USB ground connections. Simplified OPTO circuits so that they were more similar. Changed OPTO schematic symbols s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
    [USB Comms.SchDoc]
2011-07-28 5K resistors moved to outside the 10K ones on each input. Labelled the 5K resistors as optional.
    [VR Interfaces.SchDoc]
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2011-07-31 Added cap and series resistor to pressure sensor lines. Added two channels to monitor voltage on +12V CONSTANT and ACC. Moved ADC inputs for GND noise and +12V monitoring of CONSTANT AND ACC to ADC20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
    [Analog Inputs.SchDoc]
2011-07-31 Added second GND pin for INJ GND. Removed Spare Low Side Drive to allow this change.
    [Connector.SchDoc]
2011-07-31 Changed MODA and MODB to pull-down instead of pull-up. Changed NET labels for PS2 and PS3.
    [CPU.SchDoc]
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2011-07-31 Removed spare output. Changed CPU pins that were associated with majority of output stages.
    [Low Side Drivers.SchDoc]
2011-07-31 Corrected power supply circuit, now uses LM2937 for CONSTANT supply and LM2941 for SWITCHED supply.
    [Power Supplies.SchDoc]
2011-07-31 Changed 3rd sensor trickery logic gate from XOR to AND. Chenged CPU port that monitors 3rd sensor input from PA3 to PA4.
    [VR Interfaces.SchDoc]
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2011-09-17 Reformated CPU, changed all off sheet connectors to ports for I/O pins through out entire project. General tidy up of layouts. Upgraded to Revision 0.2
    [3-Wire ISCV Driver.SchDoc, Analog Inputs.SchDoc, CPU.SchDoc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]
2011-09-18 Broke analog circuits down into 2 A4 pages added format boxes and attached circuit names.
    [Analog Inputs.SchDoc, Ravage.PrjPcb]
2011-09-18 Updated CPU page with new analog setup. Added circuit names to analog circuit boxes.
    [CPU.SchDoc, Ravage.PrjPcb]
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2011-09-19 layout changes to Low Side Drivers and Digital Inputs, some name conventions corrected. Minor changes.
    [Analog Inputs 0-7.SchDoc, Analog Inputs 8-15.SchDoc, CPU.SchDoc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]
2011-09-20 Corrected circuit names, reconfigured ADC circuits and sheet ports on ADC / Connector schematics. Renamed ADC circuits to Core and Extra Analogue Inputs, updated USB layout.
    [Analog Inputs 0-7.SchDoc, Analog Inputs 8-15.SchDoc, CPU.SchDoc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]
2011-09-20 Updated page order for pdf's. Corrected more port names, some other small changes.
    [3-Wire ISCV Driver.SchDoc, CPU.SchDoc, Connector.SchDoc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]
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2011-09-21 Add game plan to get RavAGE over the line in the shortest possible time frame! :-)
2011-09-24 Corrected component values in PLL circuit.
    [CPU.SchDoc]
2011-09-24 Corrected analogue input capacitor value on all analoguue circuits.
    [Core Analogue Inputs.SchDoc, Extra Analogue Inputs.SchDoc]
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2011-09-24 Corrected minor errors. Updated PDF.
    [CPU.SchDoc]
2011-09-24 Corrected decouple cap values, fixed layout in TODO.md list. Added updated PDF.
    [CPU.SchDoc]
2011-09-25 Cleaned up layouts on PLL and Extra Analogue ciruits, all minor layout changes. Updated PDF.
    [CPU.SchDoc, Extra Analogue Inputs.SchDoc, VR Interfaces.SchDoc]
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2011-10-06 Added Knock Sensing schematic into CPU schematic bus, added data direction on ports in RS232 and USB Comms lines, added ports to Connector schematic. Tidy up of layout on both CPU and Knock pages.
    [CPU.SchDoc, Connector.SchDoc, Knock Sensing.SchDoc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]
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2011-12-13 Add not to fix RPM magic circuit and improve it making it possible to use with more complex patterns than the Toyota one.
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2011-12-16 Corrected NET labels for TX and RX CPU pins. Added expansion headers. Minor NET label changes to suit altered IO pin assignments. Updated page numbering.
    [CPU.SchDoc]
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2011-12-16 Moved spare digital inputs from IO pins A0 and A1 to J0 and J1 respectively. Updated page numbering.
    [Digital Inputs.SchDoc]
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2011-12-16 Added diode to prevent excessive reverse voltage across LEDs. Updated page numbering.
    [Injectors.SchDoc]
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2011-12-16 Updated NET labels for CPU RX and TX pins. Updated page numbering.
    [USB Comms.SchDoc]
2011-12-16 Moved RPM magic from CPU IO pin A4 to K4 and added the other channel to CPU IO pin K5. Updated page numbering.
    [VR Interfaces.SchDoc]
2011-12-16 Created SD Card schematic sheet with SD Card Interface connections and hardware for appropriate level shifting.
    [SD Card Interface.SchDoc]
2011-12-17 Corrected PK5 placement on VR Sheet. Added LEDs to ISCV drivers to prevent excessive reverse voltages.
    [3-Wire ISCV Driver.SchDoc, VR Interfaces.SchDoc]
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2011-12-23 Changed all instances of Injecter and Igniter to Injector and Ignitor. Changed all short abbreviations such as INJ1 and IGN1 to INJECTOR 1 and IGNITOR 1.
    [CPU.SchDoc, Connector.SchDoc, Igniter Outputs.SchDoc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]
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2011-12-23 Corrected TX and RX labels in sheet boxes.
    [CPU.SchDoc]
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2011-12-23 Corrected reversed comms lines that go to RS232 jack connectorto suit LC1 cable.
    [RS232 Comms.SchDoc]
2011-12-24 Fix TODO bad BOM inclusion again, hopefully for the last time now that notepad++ has been installed :-)
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2012-01-13 Swapped CPU PLL VSS and VDD pin connections so that they are correct as per datasheet.
    [CPU.SchDoc]
2012-01-13 Corrected capacitor value labelling for consistency.
    [CPU.SchDoc, Knock Sensing.SchDoc, USB Comms.SchDoc]
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2012-01-13 Fixed all direction designators.
    [CPU.SchDoc, Connector.SchDoc, Core Analogue Inputs.SchDoc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]
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2012-01-13 Corrected off-sheet connector directions, removed unnecessary crossing wires, relay of MCU sheet to maintain bus flow, matched USB sheet to remainder of project with left to right sch flow. No design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
    [3-Wire ISCV Driver.SchDoc, CPU.SchDoc, Connector.SchDoc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]
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2012-01-15 Reversed direction designators for PK4 and PK5 on VR Interface circuit.
    [CPU.SchDoc, VR Interfaces.SchDoc]
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2012-01-16 Changed CPU clock capacitor value from 22pF to 18pF and updated note on sheet to reflect capacitor tolerance type.
    [CPU.SchDoc]
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2012-01-19 Removed ADC ground and replaced with sensor ground that is linked to main CPU/reference ground NET. Added two pins for sensor ground temporarily to connector sheet in anticipation of pin re-shuffle i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
    [Connector.SchDoc, Core Analogue Inputs.SchDoc, Extra Analogue Inputs.SchDoc]
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2012-01-21 Add sm switch issue
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2012-01-22 Corrected text Cell LED to read as CEL LED.
    [CPU.SchDoc]
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2012-01-22 Changed direction of BKGD and RESET designators and changed their symbols from off-sheet connectors to port symbols.
    [CPU.SchDoc]
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2012-01-22 Reversed PJ6 and PJ7 on RTC chip. Thanks to Huff for pointing this out.
    [CPU.SchDoc]
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2012-01-22 Ammended NOTES.md file and mentioned it and the ERRATA.md file on the CPU sheet.
    [CPU.SchDoc]
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2012-01-23 Checked off previous items. Removed 2 and added 2 still to do items. Removed one wrong SD sheet todo. Added a section on connector pin ordering. Updated lock down hashes removing one for a change tha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
2012-01-23 Added wrong VR wire connections.
2012-01-29 Replaced TC427 IC with TC4427 IC.
    [Ignitor Outputs.SchDoc]
2012-01-29 Fixed reversed 1a port wires on VR sheet green box in CPU sheet.
    [CPU.SchDoc]
2012-01-29 Fixed direction of all connector sheet GND off-sheet symbols.
    [Connector.SchDoc]
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2012-01-29 Corrected text at bottom of CPU sheet that refers to md files.
    [CPU.SchDoc]
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2012-02-20 Fixed PLL circuit and made component designators match CPU datasheet.
    [CPU.SchDoc]
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2012-02-20 Specified tight tolerance resistors for setting VREG output.
    [Power Supplies.SchDoc]
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2012-02-24 Fixed GND symbol location on clock section of schematics.
    [CPU.SchDoc]
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2012-02-24 Corrected value of resistor on +12V BRV/WAKEUP LED.
    [Digital Inputs.SchDoc]
2012-03-04 Corrected connector pinout to match diagram linked in TODO list.
    [Connector.SchDoc]
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2012-03-05 Fixed layout of capacitors on CPU.
    [CPU.SchDoc]
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2012-04-30 Corrected layout of sensor ground traces and made sheet more aesthetically pleasing by grouping traces similar to the that of the connector/header pinout.
    [Connector.SchDoc]
2012-04-30 Corrected Micro SD card socket connections.
    [SD Card Interface.SchDoc]
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2012-04-30 Add in line about double checking the pin outs due to possible concurrency issues.
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2012-12-16 added correct isolators to circuit and made note regarding compatability of other isolators that have been real-world tested.
    [USB Comms.SchDoc]
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2013-01-13 Replaced 5V6 zener with 431 driven PNP clamp circuit, configured for activation at 5.15V to allow 0.35V of schottky diode drop under fault conditions.
    [Power Supplies.SchDoc]
2013-01-13 Changed note regarding resistor tolerances to read 0.1% instead of 1%.
    [Power Supplies.SchDoc]
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2013-01-24 Reconfigured Vref on TL-431 to set it at 5.15V. Removed zener text label underneath 47uF capacitor value. Removed G from MJD127 PNP transistor part designator. Corrected note regarding resistor toler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
    [Power Supplies.SchDoc]
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2013-02-04 Added NOTE stating why 10uF caps exist, based on recommendation from AN3262. Corrected LED annotations. Updated polarised cap symbols to non-polarised due to the use of MLCC's. Added NOTE next to CEL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
    [CPU.SchDoc]
2013-02-04 Created BAT721S schematic symbol and added to library. Replaced schottky diodes in anaolgue input sheets with correct dual-diode BAT721S symbol.
    [Core Analogue Inputs.SchDoc, Extra Analogue Inputs.SchDoc, FreeEMS Schematic Library.SchLib]
2013-02-04 Correct LED annotation. Removed middle resistor in digital input circuits. Changed zener values from 5v6 to 4v7. Corrected schottky diode schematic symbols to reflect dual-diode BAT721S package.
    [Digital Inputs.SchDoc]
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2013-02-04 Corrected remaining LED Annotations.
    [USB Comms.SchDoc]
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2013-02-04 Corrected NOTE to state that it allows independant use of the FET for normal purposes.
    [3-Wire ISCV Driver.SchDoc]
2013-02-04 Corrected NOTE to read intermittently instead of repeatedly.
    [USB Comms.SchDoc]
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2013-02-14 Added missing resistor between CEL and load/run circuitry to protect CPU pin. Set designator to R9.
    [CPU.SchDoc]
